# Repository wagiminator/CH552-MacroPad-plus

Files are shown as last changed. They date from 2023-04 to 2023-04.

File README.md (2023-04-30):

# CH552G MacroPad plus
The MacroPad plus is a versatile extension for your keyboard that has six programmable keys and a rotary encoder knob. These buttons and the knob can be configured to perform a variety of actions, such as triggering specific key combinations, mouse movements, and game controller inputs. You can easily modify the firmware used to operate the MacroPad to suit your needs.

Each button and knob on the MacroPad also has addressable LEDs (NeoPixels), which can be programmed in the same way as the keys. This lets you customize the colors, patterns, or animations of your device.

Connecting the MacroPad to your PC is easy - simply plug it in via USB. It's immediately recognized by your PC as an HID composite device, so no special drivers are needed. This makes the MacroPad a user-friendly and accessible option for anyone looking to enhance their keyboard's capabilities.

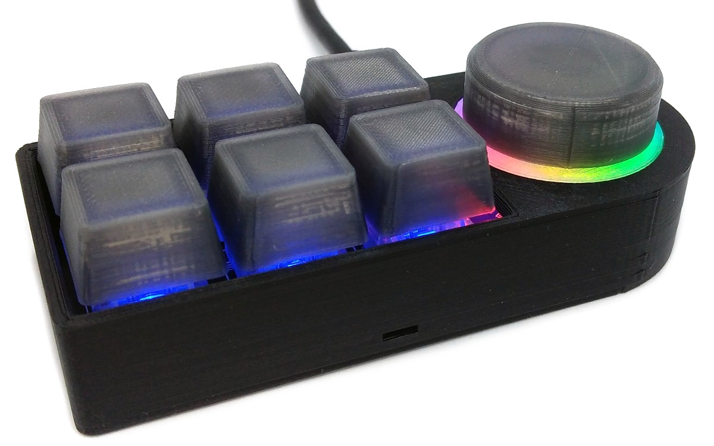
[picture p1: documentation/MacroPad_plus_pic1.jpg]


# Hardware
## Schematic
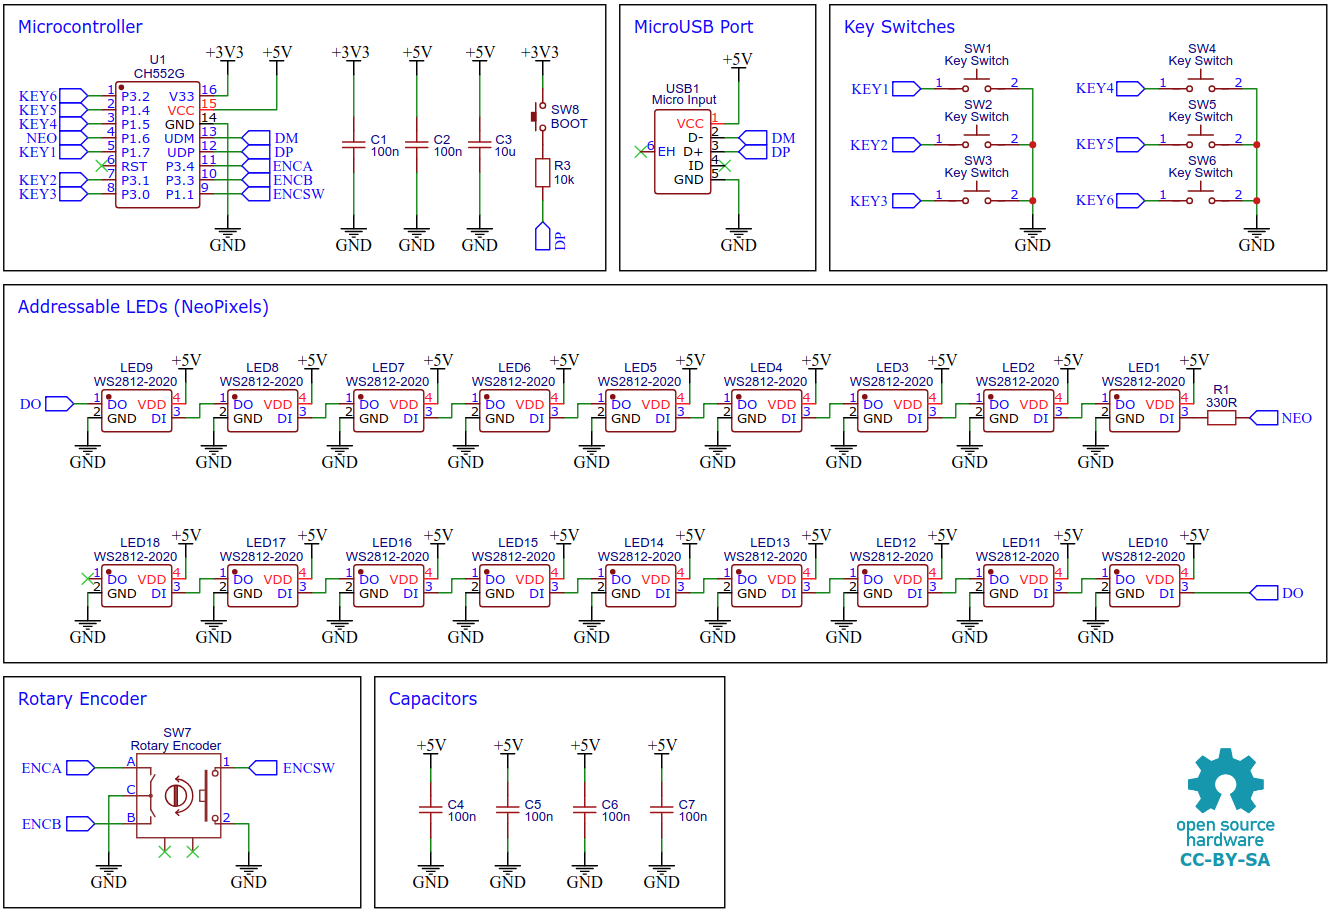
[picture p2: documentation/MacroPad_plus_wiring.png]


## CH552G 8-bit USB Device Microcontroller
The CH552G is a low-cost, enhanced E8051 core microcontroller compatible with the MCS51 instruction set. It has an integrated USB 2.0 controller with full-speed data transfer (12 Mbit/s) and supports up to 64 byte data packets with integrated FIFO and direct memory access (DMA). The CH552G has a factory built-in bootloader so firmware can be uploaded directly via USB without the need for an additional programming device.

## Buildung Instructions
1. Take the Gerber files and send them to a PCB manufacturer of your choosing. They will use these files to create the circuit board for your device.
2. Once you have the PCB, you can start soldering the components onto it. Use the BOM (bill of materials) and schematic as a guide to make sure everything is connected correctly.
3. Upload the firmware by following the instructions in the next section (see below).
4. To create the case for your device, use the STL files with your 3D printer. Make sure to use transparent filament for the keycaps, knob, and ring.
5. After printing, secure the PCB to the bottom of the case using three self-tapping M2x5mm screws.
6. Next, glue the ring from the bottom into the circular recess in the top of the case.
7. Finally, assemble the case. Place the keycaps onto the switches and the knob onto the rotary encoder. Your device is now ready to use!

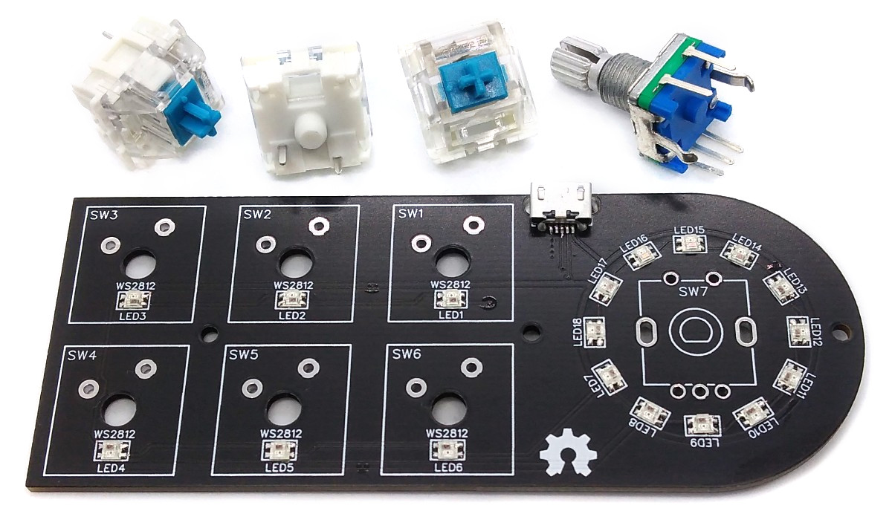
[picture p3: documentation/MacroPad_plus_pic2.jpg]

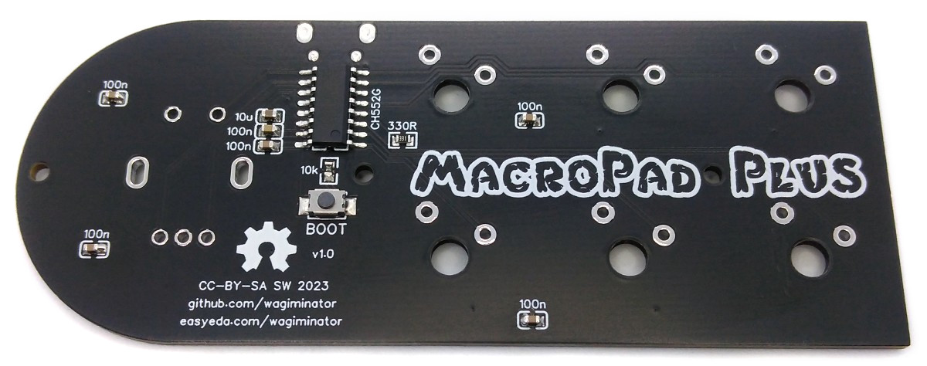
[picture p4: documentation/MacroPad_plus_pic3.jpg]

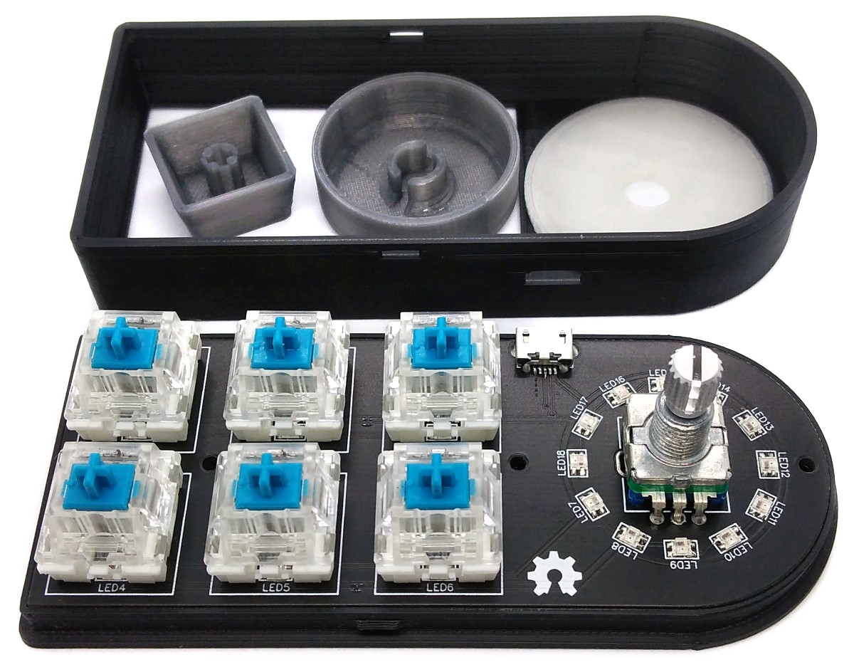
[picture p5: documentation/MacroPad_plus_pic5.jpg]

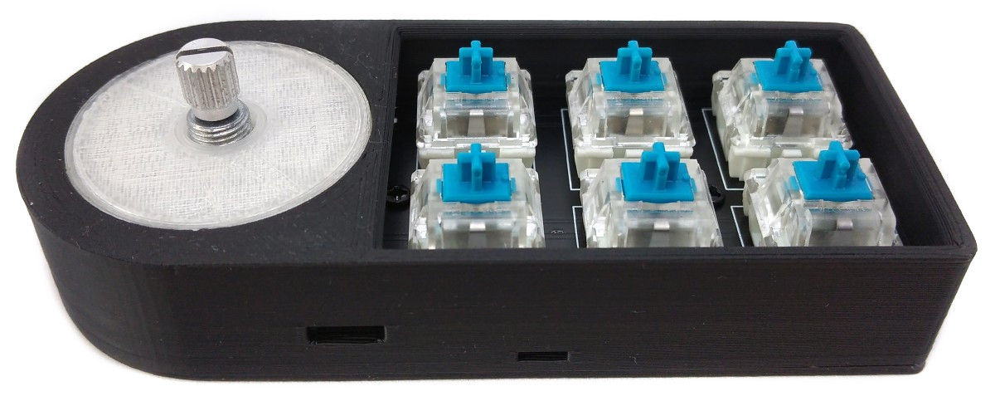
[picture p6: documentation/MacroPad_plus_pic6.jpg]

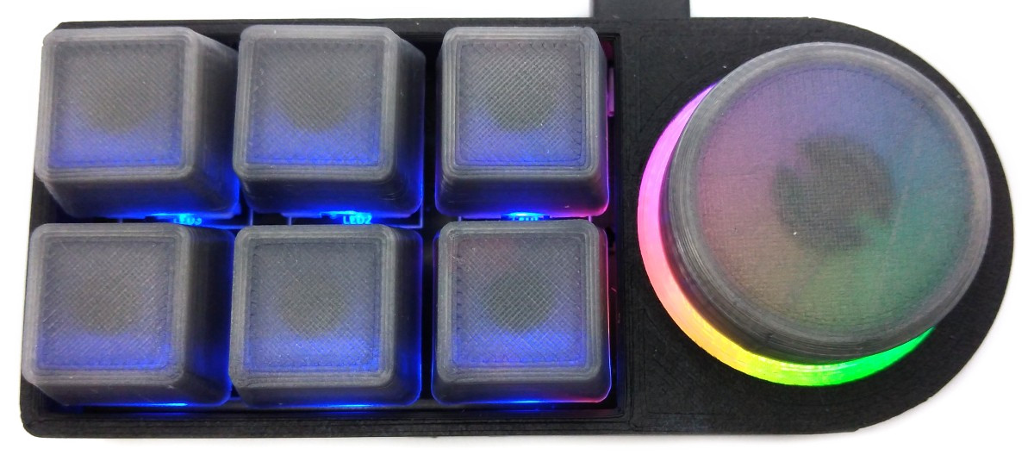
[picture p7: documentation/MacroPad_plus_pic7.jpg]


# Modifying, Compiling and Installing Firmware
## Customizing the Firmware
The definition of the macros and their assignment to individual key events is done by adjusting the firmware accordingly, which allows maximum freedom and flexibility. To do this, open the macropad_plus.c file and edit the section with the macro functions. The source code is commented in such a way that it should be possible to make adjustments even with basic programming skills.

## Preparing the CH55x Bootloader
### Installing Drivers for the CH55x Bootloader
If you're using Linux, you don't need to install a driver. However, Linux may not give you enough permission by default to upload your code with the USB bootloader. To resolve this issue, you can open a terminal and enter the following commands:

```
echo 'SUBSYSTEM=="usb", ATTR{idVendor}=="4348", ATTR{idProduct}=="55e0", MODE="666"' | sudo tee /etc/udev/rules.d/99-ch55x.rules
sudo service udev restart
```

If you're using Windows, you'll need to install the CH372 driver, which you can download from this [link](http://www.wch-ic.com/downloads/CH372DRV_EXE.html). Alternatively, you can use the [Zadig Tool](https://zadig.akeo.ie/) to install the correct driver. Simply click on "Options" and "List All Devices" to select the USB module, and then install the libusb-win32 driver. To do this, make sure the board is connected and the CH55x is in bootloader mode.

### Entering CH55x Bootloader Mode
When you connect a brand new chip to your PC via USB, it automatically starts in bootloader mode. However, after firmware has been uploaded, the bootloader must be started manually for new uploads. To do this, you need to disconnect the board from the USB port and all voltage sources, then press and hold the BOOT button while reconnecting the board to the USB port of your PC. The chip will start again in bootloader mode, and you can release the BOOT button and upload new firmware within a few seconds.

Once the MacroPad firmware is installed, you can enter the bootloader by holding down the rotary encoder switch while connecting the device to the USB port. This way, you don't need to open the case to install new firmware. All NeoPixels will light up white while the device is in bootloader mode, which lasts for about 10 seconds.

## Compiling and Uploading using the makefile
### Installing SDCC Toolchain for CH55x
Install the [SDCC Compiler](https://sdcc.sourceforge.net/). In order for the programming tool to work, Python3 must be installed on your system. To do this, follow these [instructions](https://www.pythontutorial.net/getting-started/install-python/). In addition [pyusb](https://github.com/pyusb/pyusb) must be installed. On Linux (Debian-based), all of this can be done with the following commands:

```
sudo apt install build-essential sdcc python3 python3-pip
sudo pip install pyusb
```

### Compiling and Uploading Firmware
- Open a terminal.
- Navigate to the folder with the makefile. 
- Connect the board and make sure the CH55x is in bootloader mode. 
- Run ```make flash``` to compile and upload the firmware. 
- If you don't want to compile the firmware yourself, you can also upload the precompiled binary. To do this, just run ```python3 ./tools/chprog.py macropad_plus.bin```.

## Compiling and Uploading using the Arduino IDE
### Installing the Arduino IDE and CH55xduino
Install the [Arduino IDE](https://www.arduino.cc/en/software) if you haven't already. Install the [CH55xduino](https://github.com/DeqingSun/ch55xduino) package by following the instructions on the website.

### Compiling and Uploading Firmware
- Copy the .ino and .c files as well as the /src folder together into one folder and name it like the .ino file. 
- Open the .ino file in the Arduino IDE.
- Go to **Tools -> Board -> CH55x Boards** and select **CH552 Board**.
- Go to **Tools** and choose the following board options:
  - **Clock Source:**   16 MHz (internal)
  - **Upload Method:**  USB
  - **USB Settings:**   USER CODE /w 266B USB RAM
- Connect the board and make sure the CH55x is in bootloader mode. 
- Click **Upload**.

# References, Links and Notes
1. [EasyEDA Design Files](https://oshwlab.com/wagiminator)
2. [CH551/552 Datasheet](http://www.wch-ic.com/downloads/CH552DS1_PDF.html)
3. [SDCC Compiler](https://sdcc.sourceforge.net/)
4. [MacroPad mini](https://github.com/wagiminator/CH552-Macropad-mini)
5. [USB Knob](https://github.com/wagiminator/CH552-USB-Knob)

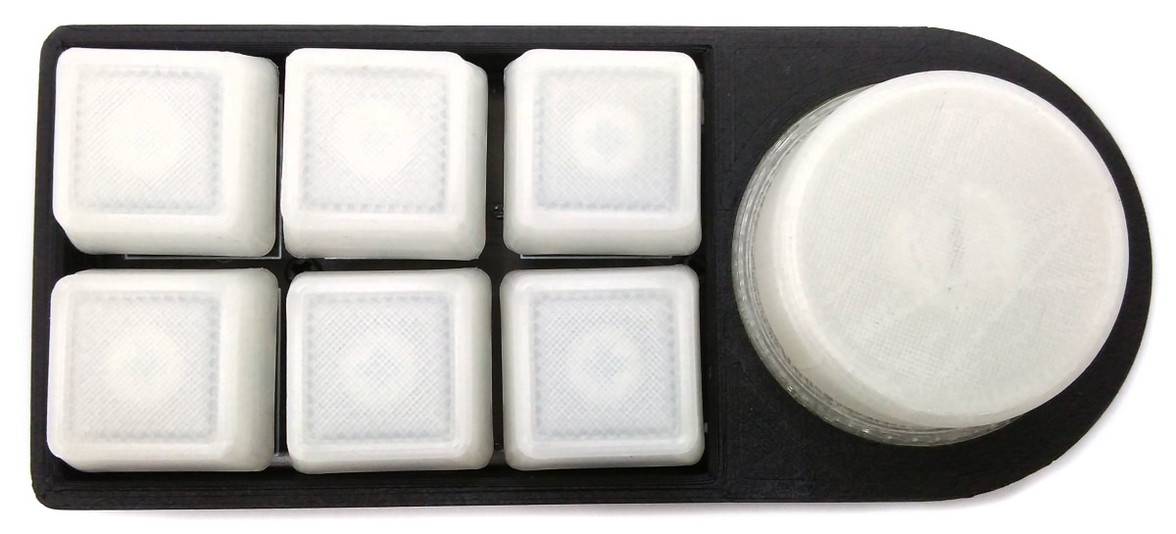
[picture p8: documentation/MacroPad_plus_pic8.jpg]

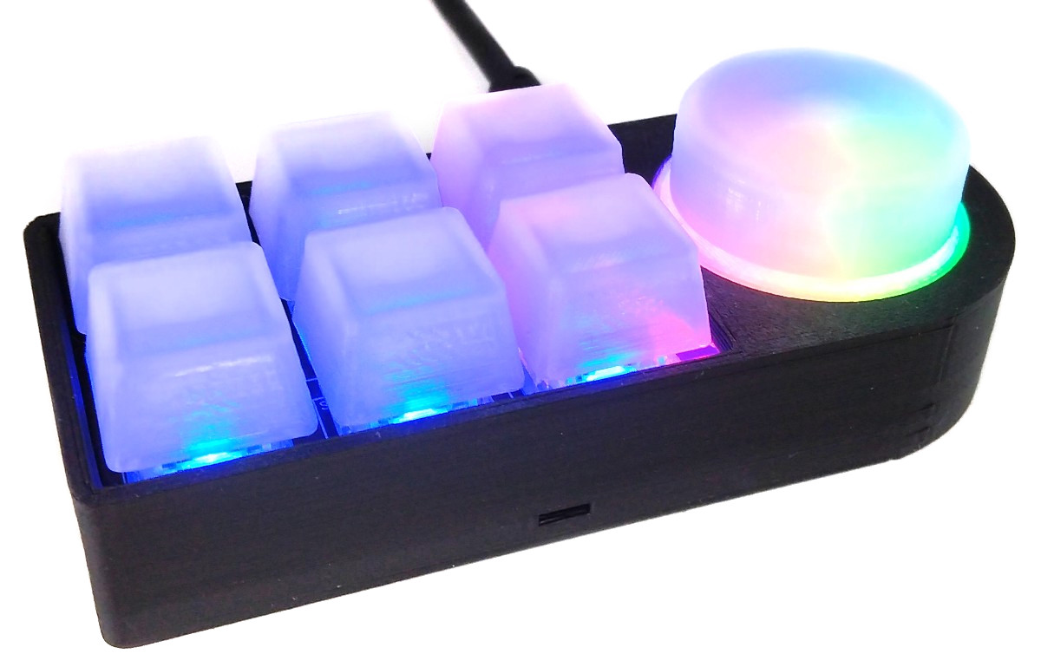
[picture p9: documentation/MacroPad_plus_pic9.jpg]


# License


This work is licensed under Creative Commons Attribution-ShareAlike 3.0 Unported License. 
(http://creativecommons.org/licenses/by-sa/3.0/)

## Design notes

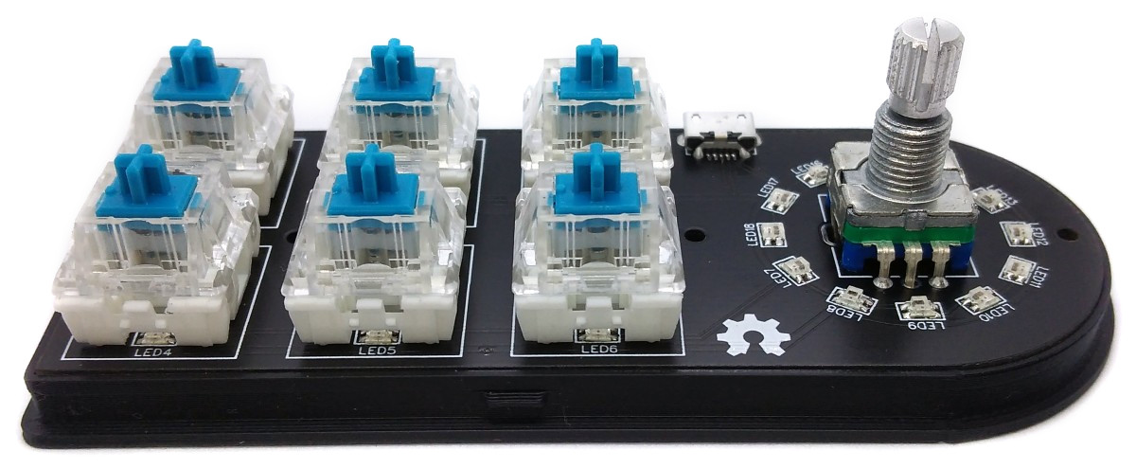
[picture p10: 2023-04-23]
documentation/MacroPad_plus_pic4.jpg

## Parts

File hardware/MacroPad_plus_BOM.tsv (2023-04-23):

ID | Name | Designator | Footprint | Quantity | Manufacturer Part | Manufacturer | Supplier | Supplier Part
1 | 100n | C1,C2,C4,C5,C6,C7 | C_0603 | 6 | CC0603KRX7R9BB104 | YAGEO | LCSC | C14663
2 | 10u | C3 | C_0603 | 1 | CL10A106KP8NNNC | SAMSUNG | LCSC | C19702
3 | WS2812-2020 | LED1,LED2,LED3,LED4,LED5,LED6,LED7,LED8,LED9,LED10,LED11,LED12,LED13,LED14,LED15,LED16,LED17,LED18 | WS2812-2020 | 18 | WS2812C-2020-V1 | worldsemi | LCSC | C2976072
4 | 330R | R1 | 0603 | 1 | 0603WAF3300T5E | UniOhm | LCSC | C23138
5 | 10k | R3 | 0603 | 1 | 0603WAF1002T5E | UniOhm | LCSC | C25804
6 | Key Switch | SW1,SW2,SW3,SW4,SW5,SW6 | KEY-TH | 6 | CPG151101D213 | Kailh(凯华) | LCSC | C400235
7 | Rotary Encoder | SW7 | ROTARY_ENCODER | 1 | PEC11R-4015F-S0024 | BOURNS | LCSC | C143789
8 | BOOT | SW8 | SW-SMD_L4.0-W2.9-LS5.0 | 1 | TS-1185-C-A-B-B | XKB Enterprise | LCSC | C465999
9 | CH552G | U1 | SOP-16_150MIL | 1 | CH552G | WCH(南京沁恒) | LCSC | C111292
10 | Micro Input | USB1 | MINI-USB-SMD_U254-051T-4BH23-S2B | 1 | U254-051T-4BH23-S2B | XKB Enterprise | LCSC | C319164

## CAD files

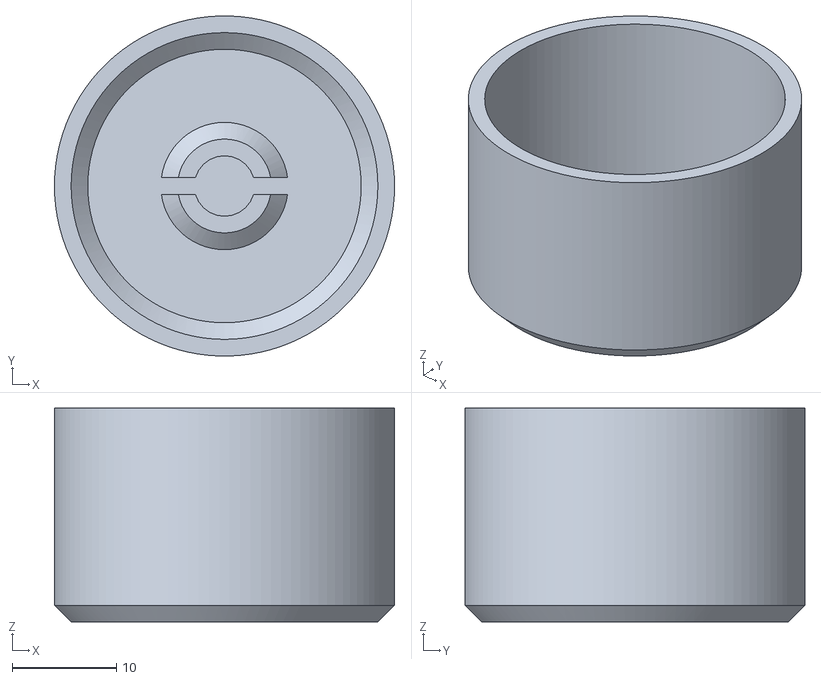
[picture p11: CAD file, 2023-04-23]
3dprint/MacroPad_plus_knob_big.stl
32.6 x 32.6 x 20.5

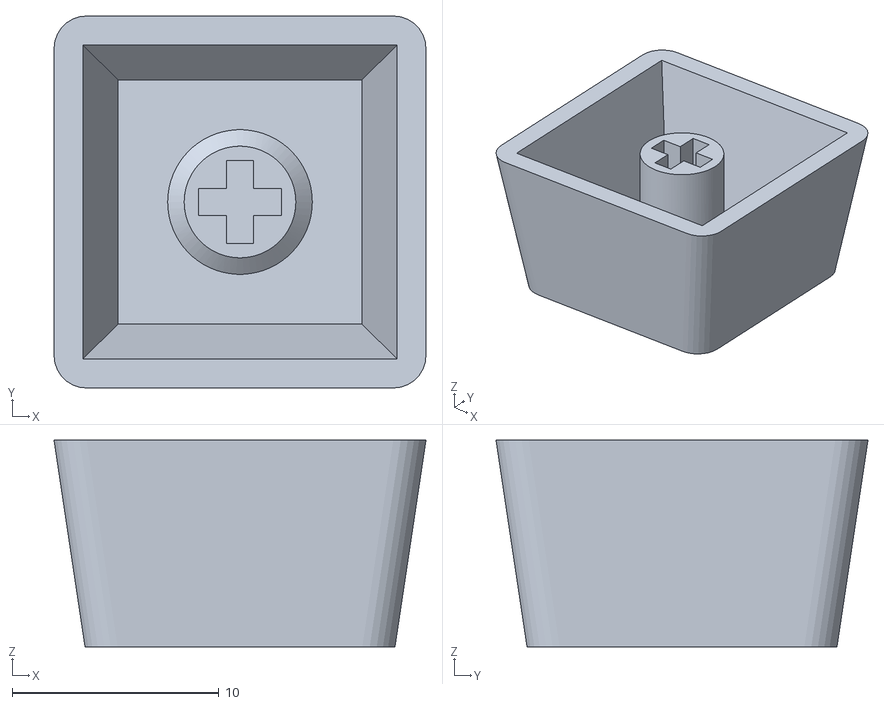
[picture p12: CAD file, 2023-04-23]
3dprint/MacroPad_plus_keycap.stl
18.0 x 18.0 x 10.0

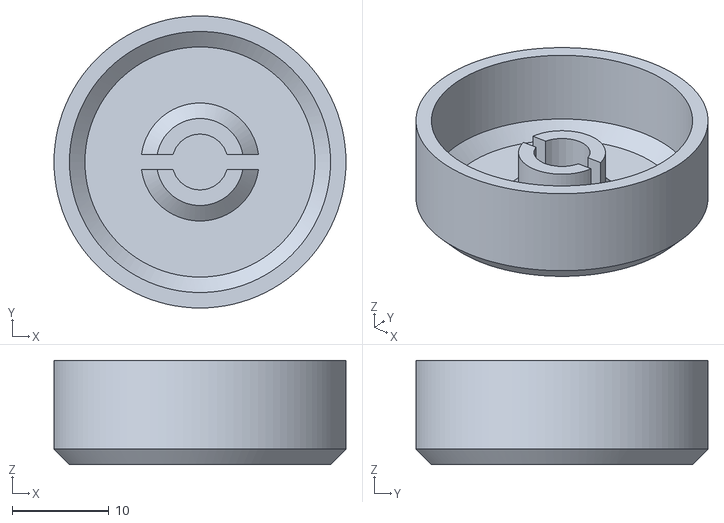
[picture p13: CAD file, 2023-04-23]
3dprint/MacroPad_plus_knob.stl
30.2 x 30.2 x 10.8

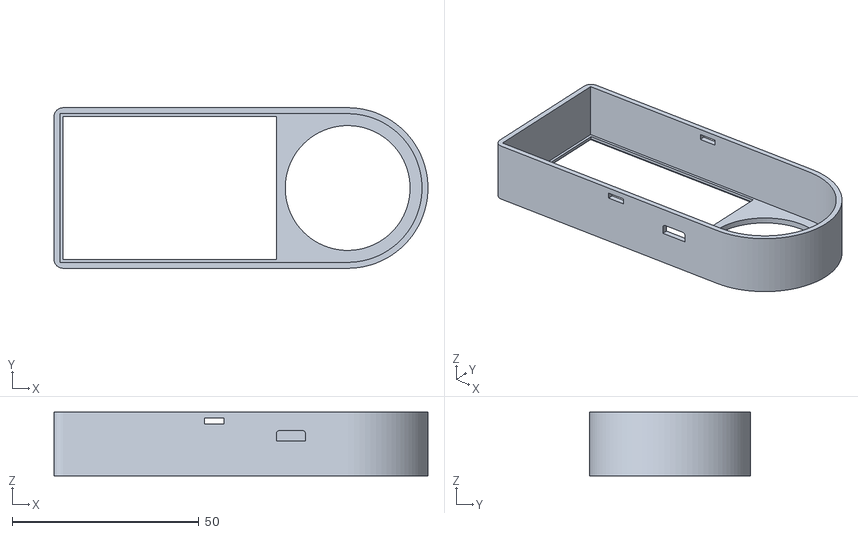
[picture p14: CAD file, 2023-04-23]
3dprint/MacroPad_plus_case_top.stl
100.1 x 43.0 x 17.0

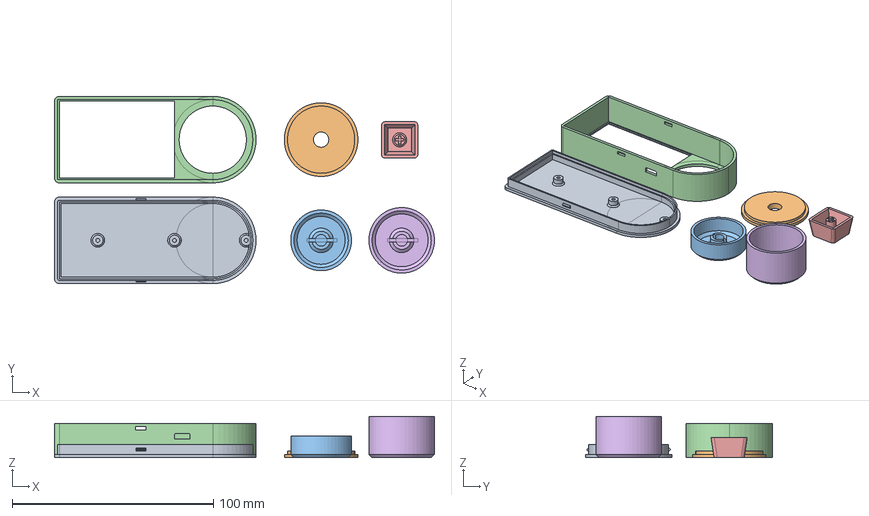
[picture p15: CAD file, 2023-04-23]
3dprint/MacroPad_plus_case.fcstd
188.7 x 93.0 x 20.5 mm
Bottom
Ring
Knob
Top
Keycap
Knob_big

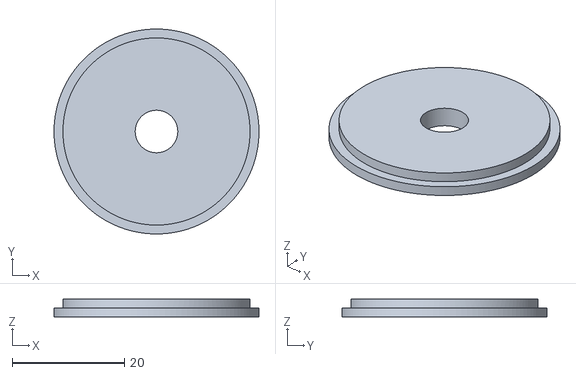
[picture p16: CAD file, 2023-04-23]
3dprint/MacroPad_plus_ring.stl
36.6 x 36.6 x 3.20

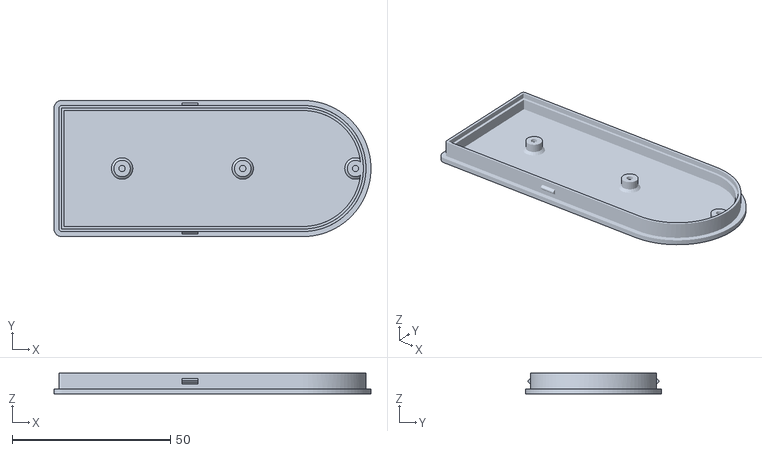
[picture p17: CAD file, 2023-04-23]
3dprint/MacroPad_plus_case_bottom.stl
100.1 x 43.0 x 6.60

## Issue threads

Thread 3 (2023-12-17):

ERROR CANNOT UPLOAD WITH ARDUINO

Le-Duc0069, 2023-12-17:
I'm having trouble uploading to Arduino. I don't know if I'm missing something. I hope you can help me.
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

wagiminator, 2023-12-18:
Did you hold down the BOOT button while connecting the device via USB? Have you ever tried it with a different board version? Have you ever tried uploading the firmware using another tool?

Le-Duc0069, 2023-12-18:
I held the boot button while installing, I used WCHISPtudio and downloaded your.bin file, and it worked, but I can't edit with Arduino
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

wagiminator, 2023-12-18:
You can try the following:
In Arduino IDE go to Sketch -> Export compiled Binary.
Then go to Sketch -> Show Sketch Folder.
Use the .bin in the folder with WCHISP.

Or try to install an older version of the board files.

Le-Duc0069, 2023-12-19:
I followed you, and didn't see the .bin file anywhere
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

wagiminator, 2023-12-20:
Then take the .hex file.

Le-Duc0069, 2023-12-21:
Get the .hex file and flash it with WCHISPtudio, right?

wagiminator, 2023-12-22:
yes

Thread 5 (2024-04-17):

Windows can't recognize USB unit

Bnor47, 2024-04-17:
Hi
Really like your project!

I'm trying to use it for a MacroPad I bought on Aliexpress. Its almost indentical to the one you have created. Only difference is that the key pins and knob pins are in another order + that it uses USB C. The difference in PINs I have modified in the file you referred to.

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

My problem is right now that it seems like I have programmed the CH552, but windows can't recognize it as a valid USB. I have struggled with this for some time and have both tried the CH375 driver and the libusb-win32 without luck.

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
Translation: "USB unit was not recognized"

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
Translation: "Unknown USB unit (not valid unit description)"

By using a bit older board version in arduino, I mannaged to get so far:
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

but still windows can't recognize it
Do you have any idea what I am missing here?

Bnor47, 2024-04-19:
I finally figured it out - not because I understand why, but it works. I had to go all the way back to version 16 of the CH552 board. Now Windows still view it as an unknown USB device; but compared to be before (v18 - 21) it is not blocked.

There is also a difference within zadiq:
It is now recognized as a HID device
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
 Before under "Driver", it simply stated "NONE"

wagiminator, 2024-04-21:
Maybe you can take a look here: https://hackaday.io/project/189914-rgb-macropad-custom-firmware

Closed 2024-04-19.

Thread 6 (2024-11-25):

Unkown USB device after downloading firmware (through ArduinoIDE)

Bruur-vr, 2024-11-25:
Hello,

Before downloading this firmware the CH552 showed up as 4 different HID devices, I did not like the firmware it came with (I had no way of changing buttons) so I tried overwriting it through ArduinoIDE. I had no problem uploading when CH552 was in bootloader mode.

I adjusted the config.h since the premade board had the switches and encoder wired differently. Also it only has 6NeoPixels.
When first connecting (with old firmware) usbview said that max load was 100mA so I changed that too.

I installed everything in ArduinoIDE, selected board and adjusted parameters under "tools". Then hit upload while it was in bootloader mode. There was something about running "make flash" but that did not work for me: I also thought you either do it through ArduinoIDE or through makefile, right?

Since the upload it shows as Unknown USB device.
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

"Windows has stopped this device because it has reported problems. (Code 43)"

Problem code is 0000002B

Events says this:
```
Device USB\VID_0000&PID_0005\5&38e97a59&0&7 was not migrated due to partial or ambiguous match.

Last Device Instance Id: USB\VID_0000&PID_0003\6&31b1809d&0&1
Class Guid: {36fc9e60-c465-11cf-8056-444553540000}
Location Path:
Migration Rank: 0xF000FFFFFFFFF100
Present: false
Status: 0xC0000719
```

in usbview it shows up like this:
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

Zadig shows up as it having no driver when out of bootloader mode.
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

When in bootloader it shows this, after I tried reïnstalling drivers (WINusb & libusb) but it makes no difference.
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

I am not well versed in these kind of topics so forgive me for not understanding in the first try.

Bruur-vr, 2024-11-25:
Good news,
I got it working.

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

The prompt to run (after doing "cd" command to the right directory):
`python3 ./tools/chprog.py macropad_plus.bin`
Did not work. It said Python was not installed (while it was). I deleted the "3" and ran it again: and there was the message you see in the image.

Bruur-vr, 2024-11-26:
Since i'm using a prebuild Macro Pad: I tried changing the parameters, like adjusting the amount of neopixels and added macro's to the keys: letting them type their own key nr. by using "KBD_type('1');" (troubleshooting what button is connected in comparison with your template).

After Uploading through Arduino the same problem persists: Unkown USB device.
The only way to get a "working" USB device is by using the  python `./tools/chprog.py macropad_plus.bin` command. But then my macro's are overwritten by the default program.

I tried export compiled binary, it gives a hex file. I put this in WCHISPstudio but after flashing I get the same "USB device not recognized" message again.
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

In a last effort I tried running:
`python ./tools/chprog.py macropad_plus.hex `
where the .hex file is outputted by ArduinoIDE, but that seemed to make the USB device not show up at all unless I reinstall CH372 driver, and then only in bootloader mode.

wagiminator, 2024-11-27:
Hi, I don't know why, but depending on the version it may not work if you compile with ArduinoIDE. If you are able to compile with the makefile, then please try this.

Bruur-vr, 2024-11-27:
Maybe the `make flash` cmd will make the right firmware?
If I try it, it returns:
```
C:\Users\xxxx\Desktop\macropad_plus>make flash
'make' is not recognized as an internal or external command,
operable program or batch file.
```
I have python 3, psyusb and SDCC installed as per instruction.

Bruur-vr, 2024-11-28:
[DeqingSun](https://github.com/DeqingSun) suggested using ch55xduino version 0.0.16, and it seemed to work.
The standard version that is installed is 0.0.25: You can downgrade it farther than 0.0.23 with ArduinoIDE legacy.

Closed 2024-11-28.

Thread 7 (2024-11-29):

EXTRA FUNCTION: Adjust LED gradient rainbow time?

Bruur-vr, 2024-11-29:
Hi,

I succesfully downloaded your firmware and made a change where the LEDs now stay on and make a rainbow pattern.
I was wondering how you would make a timer function in the macropad.c file?
I seem to be able to include time.h, but I keep getting syntax errors on using clock_t ..

```
             if(NeoHue == 191)
              {
              NeoHue = 0;
              }
             else
              {
                NeoHue += 1;
              }
      
            for (i = 0; i < 6; i += 1) // for every neopixel
              {
                NEO_writeHue(i, NeoHue, NEO_BRIGHT_KEYS);
                NEO_update();
              }
```

wagiminator, 2024-12-20:
You can use one of the timers/counters of the CH552. If precise timing is not required, I simply use a counter variable that decrements in the loop. When it reaches ZERO, the desired action is executed, and the variable is reloaded with the desired value.

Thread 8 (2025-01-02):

Not recognized after programming

tompsg-git, 2025-01-02:
I am enthusiastic about your solution and have bought a ready-made keypad. The assignment of the buttons and the Rotary are slightly different, but that was easy to change. The difference is the lack of LEDs and the USB-C connection on the board. Unfortunately, the device is not recognized after programming. I have installed another CH552 solution as a test and the device is recognized there. Do you have any idea what the problem could be? I am using Arduino IDE for the programming.

    =========================== USB Port2 ===========================

Connection Status        : 0x09 (Device is enumerating)
Port Chain               : 1-2
Properties               : 0x01
 IsUserConnectable       : yes
 PortIsDebugCapable      : no
 PortHasMultiCompanions  : no
 PortConnectorIsTypeC    : no
ConnectionIndex          : 0x02 (Port 2)
CompanionIndex           : 0
 CompanionHubSymLnk      : USB#ROOT_HUB30#4&1c077de1&0&0#{f18a0e88-c30c-11d0-8815-00a0c906bed8}
 CompanionPortNumber     : 0x0E (Port 14)
 -> CompanionPortChain   : 1-14

Used Endpoints           : 0

      ======================== USB Device ========================

DriverKeyName            : ERROR_INVALID_PARAMETER

        ---------------- Connection Information ---------------
Connection Index         : 0x00 (Port 0)
Connection Status        : 0x09 (DeviceEnumerating)
Current Config Value     : 0x00 (Configuration 0)
Device Address           : 0x00 (0)
Is Hub                   : 0x00 (no)
Device Bus Speed         : 0x00 (Low-Speed)
Number of open Pipes     : 0x00 (0 pipes to data endpoints)
Data (HexDump)           : 00 00 00 00 00 00 00 00 00 00 00 00 00 00 00 00   ................
                           00 00 00 00 00 00 00 00 00 00 00 00 00 00 00 09   ................
                           00 00 00                                          ...

        --------------- Connection Information V2 -------------
Connection Index         : 0x02 (2)
Length                   : 0x10 (16 bytes)
SupportedUsbProtocols    : 0x03
 Usb110                  : 1 (yes, port supports USB 1.1)
 Usb200                  : 1 (yes, port supports USB 2.0)
 Usb300                  : 0 (no, port not supports USB 3.0) -> but Companion Port 1-14 does
 ReservedMBZ             : 0x00
Flags                    : 0x00
 DevIsOpAtSsOrHigher     : 0 (Device is not operating at SuperSpeed or higher)
 DevIsSsCapOrHigher      : 0 (Device is not SuperSpeed capable or higher)
 DevIsOpAtSsPlusOrHigher : 0 (Device is not operating at SuperSpeedPlus or higher)
 DevIsSsPlusCapOrHigher  : 0 (Device is not SuperSpeedPlus capable or higher)
 ReservedMBZ             : 0x00
Data (HexDump)           : 02 00 00 00 10 00 00 00 03 00 00 00 00 00 00 00   ................

    ---------------------- Device Descriptor ----------------------
bLength                  : 0x00 (0 bytes)

      -------------------- String Descriptors -------------------
none

tompsg-git, 2025-01-03:
It seems to be a problem with Arduino Studio under Windows. Building and flashing from Ubuntu works good.

Closed 2025-01-03.

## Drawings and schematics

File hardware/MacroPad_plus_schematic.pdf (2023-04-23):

## Microcontroller

# P3.3 10 P3.4 11 UDP 12 UDM 13 GND 14 VCC 15 V33 16

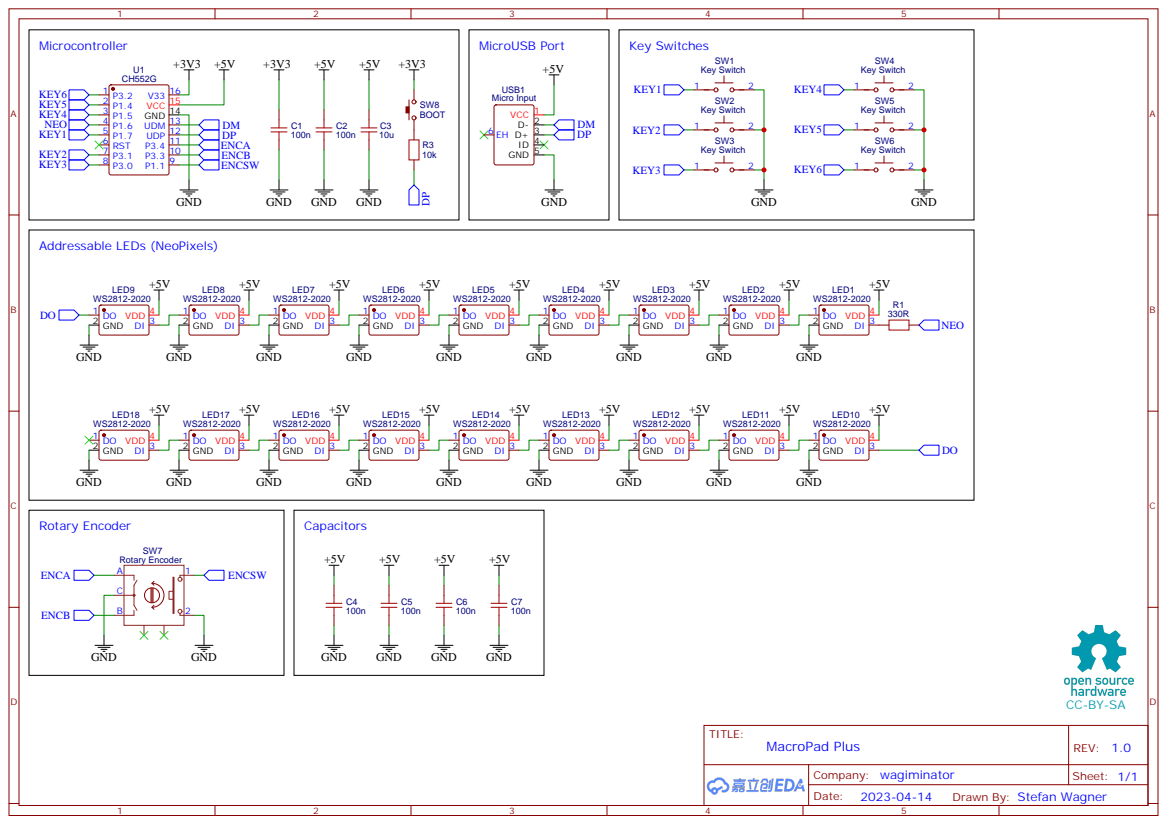
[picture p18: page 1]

Drawn By: Stefan Wagner

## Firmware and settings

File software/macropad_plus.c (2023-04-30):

// ===================================================================================
// Project:   MacroPad Plus for CH551, CH552 and CH554
// Version:   v1.0
// Year:      2023
// Author:    Stefan Wagner
// Github:    https://github.com/wagiminator
// EasyEDA:   https://easyeda.com/wagiminator
// License:   http://creativecommons.org/licenses/by-sa/3.0/
// ===================================================================================
//
// Description:
// ------------
// Firmware example implementation for the MacroPad Plus.
//
// References:
// -----------
// - Blinkinlabs: https://github.com/Blinkinlabs/ch554_sdcc
// - Deqing Sun: https://github.com/DeqingSun/ch55xduino
// - Ralph Doncaster: https://github.com/nerdralph/ch554_sdcc
// - WCH Nanjing Qinheng Microelectronics: http://wch.cn
//
// Compilation Instructions:
// -------------------------
// - Chip:  CH551, CH552 or CH554
// - Clock: 16 MHz internal
// - Adjust the firmware parameters in src/config.h if necessary.
// - Customize the macro functions in the corresponding section below.
// - Make sure SDCC toolchain and Python3 with PyUSB is installed.
// - Press BOOT button on the board and keep it pressed while connecting it via USB
//   with your PC.
// - Run 'make flash' immediatly afterwards.
// - To compile the firmware using the Arduino IDE, follow the instructions in the 
//   .ino file.
//
// Operating Instructions:
// -----------------------
// - Connect the board via USB to your PC. It should be detected as a HID device with
//   keyboard, mouse and joystick interface.
// - Press a macro key or turn the knob and see what happens.
// - To enter bootloader hold down rotary encoder switch while connecting the 
//   MacroPad to USB. All NeoPixels will light up white as long as the device is in 
//   bootloader mode (about 10 seconds).


// ===================================================================================
// Libraries, Definitions and Macros
// ===================================================================================

// Libraries
#include "src/config.h"                     // user configurations
#include "src/system.h"                     // system functions
#include "src/delay.h"                      // delay functions
#include "src/neo.h"                        // NeoPixel functions
#include "src/usb_composite.h"              // USB HID composite functions

// Prototypes for used interrupts
void USB_interrupt(void);
void USB_ISR(void) __interrupt(INT_NO_USB) {
  USB_interrupt();
}

#pragma disable_warning 110                 // Keep calm, EVELYN!

// ===================================================================================
// Macro Functions which associate Actions with Events (Customize your MacroPad here!)
// ===================================================================================
/*
// The list of available USB HID functions can be found in src/usb_composite.h
// The keys are enumerated the following way:
// +---+---+---+    -----
// | 3 | 2 | 1 |  /       \
// +---+---+---+  |encoder|
// | 4 | 5 | 6 |  \       /
// +---+---+---+    -----
*/

// Key 1 example -> mouse wheel up (scroll page)
// ---------------------------------------------

// Define action(s) if key1 was pressed
inline void KEY1_PRESSED() {
                                                      // nothing to do
}

// Define action(s) if key1 was released
inline void KEY1_RELEASED() {
                                                      // nothing to do
}

// Define action(s) when key1 is held
inline void KEY1_HOLD() {
  MOUSE_wheel_up();                                   // turn mouse wheel up
  DLY_ms(10);                                         // delay
}

// Key 2 example -> ALT + TAB (switch application)
// -----------------------------------------------

// Define action(s) if key2 was pressed
inline void KEY2_PRESSED() {
  KBD_press(KBD_KEY_LEFT_ALT);                        // press left ALT key
}

// Define action(s) if key2 was released
inline void KEY2_RELEASED() {
  KBD_release(KBD_KEY_LEFT_ALT);                      // release left ALT key
}

// Define action(s) when key2 is held
inline void KEY2_HOLD() {
  KBD_type(KBD_KEY_TAB);                              // press and release TAB key
  DLY_ms(500);                                        // delay
}

// Key 3 example -> WIN + DOWN ARROW (show apps)
// ---------------------------------------------

// Define action(s) if key3 was pressed
inline void KEY3_PRESSED() {
  KBD_press(KBD_KEY_LEFT_GUI);                        // press left WIN key
  KBD_press(KBD_KEY_DOWN_ARROW);                      // press DOWN ARROW key
}

// Define action(s) if key3 was released
inline void KEY3_RELEASED() {
  KBD_release(KBD_KEY_DOWN_ARROW);                    // release DOWN ARROW key
  KBD_release(KBD_KEY_LEFT_GUI);                      // release left WIN key
}

// Define action(s) when key3 is held
inline void KEY3_HOLD() {
                                                      // nothing to do
}

// Key 4 example -> CTRL + ALT + DEL (shutdown)
// --------------------------------------------

// Define action(s) if key4 was pressed
inline void KEY4_PRESSED() {
  KBD_press(KBD_KEY_LEFT_CTRL);                       // press left CTRL key
  KBD_press(KBD_KEY_LEFT_ALT);                        // press left ALT key
  KBD_press(KBD_KEY_DELETE);                          // press DEL key
}

// Define action(s) if key4 was released
inline void KEY4_RELEASED() {
  KBD_release(KBD_KEY_DELETE);                        // release DEL key
  KBD_release(KBD_KEY_LEFT_ALT);                      // release left ALT key
  KBD_release(KBD_KEY_LEFT_CTRL);                     // release left CTRL key
}

// Define action(s) when key4 is held
inline void KEY4_HOLD() {
                                                      // nothing to do
}

// Key 5 example -> Linux open terminal and run shutdown command
// -------------------------------------------------------------

// Define action(s) if key5 was pressed
inline void KEY5_PRESSED() {
  KBD_press(KBD_KEY_LEFT_GUI);                        // press left WIN key
  KBD_type('t');                                      // press and release 'T' key
  DLY_ms(500);                                        // wait for terminal to open
  KBD_release(KBD_KEY_LEFT_GUI);                      // release left WIN key
  KBD_print("sudo shutdown -h now");                  // type shutdown command
  KBD_type(KBD_KEY_RETURN);                           // press and release RETURN key
}

// Define action(s) if key5 was released
inline void KEY5_RELEASED() {
                                                      // nothing to do
}

// Define action(s) when key5 is held
inline void KEY5_HOLD() {
                                                      // nothing to do
}

// Key 6 example -> mouse wheel down (scroll page)
// -----------------------------------------------

// Define action(s) if key6 was pressed
inline void KEY6_PRESSED() {
                                                      // nothing to do
}

// Define action(s) if key6 was released
inline void KEY6_RELEASED() {
                                                      // nothing to do
}

// Define action(s) when key6 is held
inline void KEY6_HOLD() {
  MOUSE_wheel_down();                                 // turn mouse wheel down
  DLY_ms(10);                                         // delay
}

// Rotary encoder example -> volume control knob
// ---------------------------------------------

// Define action(s) if encoder was rotated clockwise
inline void ENC_CW_ACTION() {
  CON_press(CON_VOL_UP);                              // press VOLUME UP key
}

// Define action(s) after encoder was rotated clockwise
inline void ENC_CW_RELEASED() {
  CON_release();                                      // release VOLUME UP KEY
}

// Define action(s) if encoder was rotated counter-clockwise
inline void ENC_CCW_ACTION() {
  CON_press(CON_VOL_DOWN);                            // press VOLUME DOWN key
}

// Define action(s) after encoder was rotated counter-clockwise
inline void ENC_CCW_RELEASED() {
  CON_release();                                      // release VOLUME DOWN KEY
}

// Define action(s) if encoder switch was pressed
inline void ENC_SW_PRESSED() {
  CON_press(CON_VOL_MUTE);                            // press VOLUME MUTE key
}

// Define action(s) if encoder switch was released
inline void ENC_SW_RELEASED() {
  CON_release();                                      // release VOLUME MUTE key
}

// ===================================================================================
// NeoPixel Configuration
// ===================================================================================

// Global NeoPixel brightness
#define NEO_BRIGHT_KEYS   2         // NeoPixel brightness for keys (0..2)
#define NEO_BRIGHT_ENC    0         // NeoPixel brightness for encoder ring (0..2)

// Key colors (hue value: 0..191)
#define NEO_KEY1          0         // red
#define NEO_KEY2          32        // yellow
#define NEO_KEY3          64        // green
#define NEO_KEY4          96        // cyan
#define NEO_KEY5          128       // blue
#define NEO_KEY6          160       // magenta

// ===================================================================================
// NeoPixel Functions
// ===================================================================================

uint8_t neoencoder = 0;                           // state of NeoPixel ring rotation

// Update NeoPixel ring colors
void NEO_encoder_update(void) {
  uint8_t i, j;
  j = neoencoder;
  for(i=6; i<18; i++) {
    NEO_writeHue(i, j, NEO_BRIGHT_ENC);
    j += 16;
    if(j >= 192) j -= 192;
  }
  NEO_update();
}

// Rotate NeoPixel ring clockwise
void NEO_encoder_cw(void) {
  neoencoder += 8;
  if(neoencoder >= 192) neoencoder -= 192;
  NEO_encoder_update();
}

// Rotate NeoPixel ring counter-clockwise
void NEO_encoder_ccw(void) {
  neoencoder -= 8;
  if(neoencoder >= 192) neoencoder -= 64;
  NEO_encoder_update();
}

// ===================================================================================
// Main Function
// ===================================================================================
void main(void) {
  // Variables
  __bit key1last = 0;                             // last state of key 1
  __bit key2last = 0;                             // last state of key 2
  __bit key3last = 0;                             // last state of key 3
  __bit key4last = 0;                             // last state of key 4
  __bit key5last = 0;                             // last state of key 5
  __bit key6last = 0;                             // last state of key 6
  __bit isSwitchPressed = 0;                      // state of rotary encoder switch
  __idata uint8_t i;                              // temp variable

  // Setup
  NEO_init();                                     // init NeoPixels
  CLK_config();                                   // configure system clock
  DLY_ms(10);                                     // wait for clock to settle
  NEO_clearAll();                                 // clear NeoPixels

  // Enter bootloader if rotary encoder switch is pressed
  if(!PIN_read(PIN_ENC_SW)) {                     // encoder switch pressed?
    for(i=3*NEO_COUNT; i; i--) NEO_sendByte(127); // light up all pixels
    BOOT_now();                                   // enter bootloader
  }

  // Init USB HID device
  HID_init();                                     // init USB HID device
  DLY_ms(500);                                    // wait for Windows
  WDT_start();                                    // start watchdog timer
  NEO_encoder_update();                           // set NeoPixel ring for encoder

  // Loop
  while(1) {

    // Handle key 1
    // ------------
    if(!PIN_read(PIN_KEY1) != key1last) {         // key state changed?
      key1last = !key1last;                       // update last state flag
      if(key1last) {                              // key was pressed?
        NEO_writeHue(0, NEO_KEY1, NEO_BRIGHT_KEYS);    // light up corresponding NeoPixel
        NEO_update();                             // update pixels
        KEY1_PRESSED();                           // take proper action
      }
      else {                                      // key was released?
        NEO_clearPixel(0);                        // light up corresponding NeoPixel
        NEO_update();                             // update pixels
        KEY1_RELEASED();                          // take proper action
      }
    }
    else if(key1last) {                           // key still being pressed?
      KEY1_HOLD();                                // take proper action
    }

    // Handle key 2
    // ------------
    if(!PIN_read(PIN_KEY2) != key2last) {         // key state changed?
      key2last = !key2last;                       // update last state flag
      if(key2last) {                              // key was pressed?
        NEO_writeHue(1, NEO_KEY2, NEO_BRIGHT_KEYS);    // light up corresponding NeoPixel
        NEO_update();                             // update pixels
        KEY2_PRESSED();                           // take proper action
      }
      else {                                      // key was released?
        NEO_clearPixel(1);                        // light up corresponding NeoPixel
        NEO_update();                             // update pixels
        KEY2_RELEASED();                          // take proper action
      }
    }
    else if(key2last) {                           // key still being pressed?
      KEY2_HOLD();                                // take proper action
    }

    // Handle key 3
    // ------------
    if(!PIN_read(PIN_KEY3) != key3last) {         // key state changed?
      key3last = !key3last;                       // update last state flag
      if(key3last) {                              // key was pressed?
        NEO_writeHue(2, NEO_KEY3, NEO_BRIGHT_KEYS);    // light up corresponding NeoPixel
        NEO_update();                             // update pixels
        KEY3_PRESSED();                           // take proper action
      }
      else {                                      // key was released?
        NEO_clearPixel(2);                        // light up corresponding NeoPixel
        NEO_update();                             // update pixels
        KEY3_RELEASED();                          // take proper action
      }
    }
    else if(key3last) {                           // key still being pressed?
      KEY3_HOLD();                                // take proper action
    }

    // Handle key 4
    // ------------
    if(!PIN_read(PIN_KEY4) != key4last) {         // key state changed?
      key4last = !key4last;                       // update last state flag
      if(key4last) {                              // key was pressed?
        NEO_writeHue(3, NEO_KEY4, NEO_BRIGHT_KEYS);    // light up corresponding NeoPixel
        NEO_update();                             // update pixels
        KEY4_PRESSED();                           // take proper action
      }
      else {                                      // key was released?
        NEO_clearPixel(3);                        // light up corresponding NeoPixel
        NEO_update();                             // update pixels
        KEY4_RELEASED();                          // take proper action
      }
    }
    else if(key4last) {                           // key still being pressed?
      KEY4_HOLD();                                // take proper action
    }

    // Handle key 5
    // ------------
    if(!PIN_read(PIN_KEY5) != key5last) {         // key state changed?
      key5last = !key5last;                       // update last state flag
      if(key5last) {                              // key was pressed?
        NEO_writeHue(4, NEO_KEY5, NEO_BRIGHT_KEYS);    // light up corresponding NeoPixel
        NEO_update();                             // update pixels
        KEY5_PRESSED();                           // take proper action
      }
      else {                                      // key was released?
        NEO_clearPixel(4);                        // light up corresponding NeoPixel
        NEO_update();                             // update pixels
        KEY5_RELEASED();                          // take proper action
      }
    }
    else if(key5last) {                           // key still being pressed?
      KEY5_HOLD();                                // take proper action
    }

    // Handle key 6
    // ------------
    if(!PIN_read(PIN_KEY6) != key6last) {         // key state changed?
      key6last = !key6last;                       // update last state flag
      if(key6last) {                              // key was pressed?
        NEO_writeHue(5, NEO_KEY6, NEO_BRIGHT_KEYS);    // light up corresponding NeoPixel
        NEO_update();                             // update pixels
        KEY6_PRESSED();                           // take proper action
      }
      else {                                      // key was released?
        NEO_clearPixel(5);                        // light up corresponding NeoPixel
        NEO_update();                             // update pixels
        KEY6_RELEASED();                          // take proper action
      }
    }
    else if(key6last) {                           // key still being pressed?
      KEY6_HOLD();                                // take proper action
    }

    // Handle rotary encoder
    // ---------------------
    if(!PIN_read(PIN_ENC_A)) {                    // encoder turned ?
      if(PIN_read(PIN_ENC_B)) {                   // clockwise ?
        ENC_CW_ACTION();                          // take proper action
        NEO_encoder_cw();                         // rotate NeoPixels
        DLY_ms(5);                                // debounce
        ENC_CW_RELEASED();                        // take proper action
      }
      else {                                      // counter-clockwise ?
        ENC_CCW_ACTION();                         // take proper action
        NEO_encoder_ccw();                        // rotate NeoPixels
        DLY_ms(5);                                // debounce
        ENC_CCW_RELEASED();                       // take proper action
      }
      while(!PIN_read(PIN_ENC_A));                // wait until next detent
    } 
    else {
      if(!isSwitchPressed && !PIN_read(PIN_ENC_SW)) {     // switch previously pressed?
        ENC_SW_PRESSED();                         // take proper action
        isSwitchPressed = 1;
      }
      else if(isSwitchPressed && PIN_read(PIN_ENC_SW)) {  // switch previously released?
        ENC_SW_RELEASED();                        // take proper action
        isSwitchPressed = 0;                      // update switch state
      }
    }

    DLY_ms(1);                                    // debounce
    WDT_reset();                                  // reset watchdog
  }
}

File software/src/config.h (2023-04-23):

// ===================================================================================
// User Configurations for CH552G USB MacroPad Plus
// ===================================================================================

#pragma once

// Pin definitions
#define PIN_NEO             P16         // pin connected to NeoPixel
#define PIN_KEY1            P17         // pin connected to key 1
#define PIN_KEY2            P31         // pin connected to key 2
#define PIN_KEY3            P30         // pin connected to key 3
#define PIN_KEY4            P15         // pin connected to key 4
#define PIN_KEY5            P14         // pin connected to key 5
#define PIN_KEY6            P32         // pin connected to key 6
#define PIN_ENC_A           P34         // pin connected to rotary encoder A
#define PIN_ENC_B           P33         // pin connected to rotary encoder B
#define PIN_ENC_SW          P11         // pin connected to rotary encoder switch

// NeoPixel configuration
#define NEO_COUNT           18          // number of pixels in the string
#define NEO_GRB                         // type of pixel: NEO_GRB or NEO_RGB

// USB device descriptor
#define USB_VENDOR_ID       0x1189      // VID
#define USB_PRODUCT_ID      0x8890      // PID
#define USB_DEVICE_VERSION  0x0100      // v1.0 (BCD-format)

// USB configuration descriptor
#define USB_MAX_POWER_mA    150         // max power in mA 

// USB descriptor strings
#define MANUFACTURER_STR    'w','a','g','i','m','i','n','a','t','o','r'
#define PRODUCT_STR         'M','a','c','r','o','P','a','d'
#define SERIAL_STR          'C','H','5','5','2','x','H','I','D'
#define INTERFACE_STR       'H','I','D','-','K','e','y','b','o','a','r','d'
